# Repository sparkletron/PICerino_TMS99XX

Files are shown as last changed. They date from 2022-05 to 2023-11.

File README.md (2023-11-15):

# PICerino TMS VDP

Test Board and Software Library for TI TMS992X and TMS9118 video display processors.

author: Jay Convertino  

date: 2022.04.23  

license: MIT (software/Hardware)

## Release Versions
### Current
  - v2.1.0 - Improved video circuit for the TMS9118.

### Past
  - v2.0.0 - Improved video circuit that actually works.
  - v1.0.0 - Improved video circuit and TMS9118 schematic added.
  - v0.5.0 - First version with old video circuit.
  - none
  
## Requirements
### Hardware
  - KiCad
  
### Software
  - xc8 compiler
  
## Information

### Directory Listing:

  - docs - Data documents for various ICs.
  - schematic - KiCad schematic
    - TMS9118 - Contains a schematic for a TMS9118 board with video circuit (v2).
    - TMS992X - Contains a schematic for a TMS992X board with video circuit (v2).
  - src - Any source code for the project.
    - lib_picTMS99XX folder contains a library with test program for picerino. See readme.md in this directory for details.

### Usage
  This is made to be used with the picerino development board. This uses the standard DRAM since there are plenty of them around from various venders. The idea is the test program with put the card through its paces. This is done by putting the VDP into all modes and testing all of its functions. Currently this is incomplete. GFX II, various sprite sizes and edge cases need testing. The other idea with this was to create a simple video circuit for YrYbY output to go to an upscaler and then to HDMI. The retrotink 2x works well with the output of this unit.

### Build
  Through hole components were selected for everything, except for the video circuit of the TMS9118. This something I had on hand. Production uses a double sided board.

### Video Output
  This video circuit is based on a few ideas. Mostly TMS-RGB for the use of the LM1881. All other design choices are from application datasheets and just trial and error. Main issue with TMS-RGB being used whole sale is it has all surface mount components and it isn't universal for TMS9918. The goal of this project was to output component or composite to the retro tink x2. TI's application data sheet is keying out the Yr/Yb color bursts with a decoulping cap passing the signal to a 4066 that just went to ground during sync. This in theory should work fine, but in practice you'll still see a bit of the burst. TMS-RGB used a sample and hold method, which worked great to the converter chip. Taking the TMS RGB and just using a quad switch to sample the Yb signal, then pass it to the other inputs that then use that sample when needed (see lm1881 connections). This method of using a quad switch eliminates the too much blue issue. It also results in a circuit that is only 3 ic's. A MAX394, ADG813, and LM1881. The opamp is setup to rebalance the colors per the TMS RGB Y+Yr+Yb findings. Again big thanks to them for spending the time to document how and what they did. Saved me a lot of work on this project.

### Issues
  N/A

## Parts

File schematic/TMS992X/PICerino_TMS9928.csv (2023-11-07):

# | Reference | Qty | Value | Footprint | DNP
1 | C1 | 1 | 10uF | Capacitor_THT:CP_Radial_D5.0mm_P2.50mm
2 | C2, C3, C4, C5, C6, C7, C8, C9, C13, C15, C16, C18, C19, C20, C23 | 15 | 100nF | Capacitor_THT:C_Disc_D4.7mm_W2.5mm_P5.00mm
3 | C10 | 1 | 2-5pf | Capacitor_THT:C_Rect_L10.0mm_W5.0mm_P5.00mm_P7.50mm
4 | C11 | 1 | 30pF | Capacitor_THT:C_Disc_D3.0mm_W1.6mm_P2.50mm
5 | C12 | 1 | 33pF | Capacitor_THT:C_Disc_D3.0mm_W1.6mm_P2.50mm
6 | C14, C27, C28 | 3 | 33uF | Capacitor_THT:CP_Radial_D5.0mm_P2.50mm
7 | C17, C21, C24, C26 | 4 | 220pf | Capacitor_THT:C_Disc_D4.7mm_W2.5mm_P5.00mm
8 | C22, C29, C30 | 3 | 470uF | Capacitor_THT:CP_Radial_D8.0mm_P5.00mm
9 | C25 | 1 | 10nF | Capacitor_THT:C_Disc_D4.7mm_W2.5mm_P5.00mm
10 | CON1 | 1 | PICERINO-EDGE | Connector_PCBEdge_EXT:PICERINO-EDGE
11 | D1 | 1 | D_Schottky | Diode_THT:D_DO-35_SOD27_P7.62mm_Horizontal
12 | J1 | 1 | Conn_01x02 | Connector_PinHeader_2.54mm:PinHeader_1x02_P2.54mm_Vertical
13 | J2, J3, J4, J10 | 4 | Conn_01x03 | Connector_PinHeader_2.54mm:PinHeader_1x03_P2.54mm_Vertical
14 | J5 | 1 | Y | RCJ-041:RCJ041_TS
15 | J6 | 1 | Yr | RCJ-041:RCJ041_TS
16 | J7 | 1 | Yb | RCJ-041:RCJ041_TS
17 | J8, J9 | 2 | Conn_01x08 | Package_SIP:SIP-8_19x3mm_P2.54mm
18 | R1 | 1 | 10K | Resistor_THT:R_Axial_DIN0207_L6.3mm_D2.5mm_P7.62mm_Horizontal
19 | R2, R4, R12, R13, R14 | 5 | 510R | Resistor_THT:R_Axial_DIN0207_L6.3mm_D2.5mm_P7.62mm_Horizontal
20 | R5 | 1 | 680k | Resistor_THT:R_Axial_DIN0207_L6.3mm_D2.5mm_P7.62mm_Horizontal
21 | R6 | 1 | 430R | Resistor_THT:R_Axial_DIN0207_L6.3mm_D2.5mm_P7.62mm_Horizontal
22 | R7, R9, R10 | 3 | 470R | Resistor_THT:R_Axial_DIN0207_L6.3mm_D2.5mm_P7.62mm_Horizontal
23 | R8, R17, R18 | 3 | 75R | Resistor_THT:R_Axial_DIN0207_L6.3mm_D2.5mm_P7.62mm_Horizontal
24 | R11 | 1 | 1K | Resistor_THT:R_Axial_DIN0207_L6.3mm_D2.5mm_P7.62mm_Horizontal
25 | R15 | 1 | 200R | Resistor_THT:R_Axial_DIN0207_L6.3mm_D2.5mm_P7.62mm_Horizontal
26 | R16 | 1 | 270R | Resistor_THT:R_Axial_DIN0207_L6.3mm_D2.5mm_P7.62mm_Horizontal
27 | TP1, TP2 | 2 | TestPoint | Connector_PinHeader_2.54mm:PinHeader_1x01_P2.54mm_Vertical
28 | U1 | 1 | LM1881 | Package_DIP:DIP-8_W7.62mm_LongPads
29 | U2 | 1 | AD813 | Package_DIP:DIP-14_W7.62mm_LongPads
30 | U3 | 1 | TMS9928A | Package_DIP:DIP-40_W15.24mm_LongPads
31 | U4 | 1 | NE5532 | Package_DIP:DIP-8_W7.62mm_LongPads
32 | U5, U6, U8, U9, U10, U11, U12, U13 | 8 | MK4516N | Package_DIP:DIP-16_W7.62mm_LongPads
33 | U7 | 1 | ADG453 | Package_DIP:DIP-16_W7.62mm_LongPads
34 | Y1 | 1 | Crystal | Crystal:Crystal_HC49-4H_Vertical

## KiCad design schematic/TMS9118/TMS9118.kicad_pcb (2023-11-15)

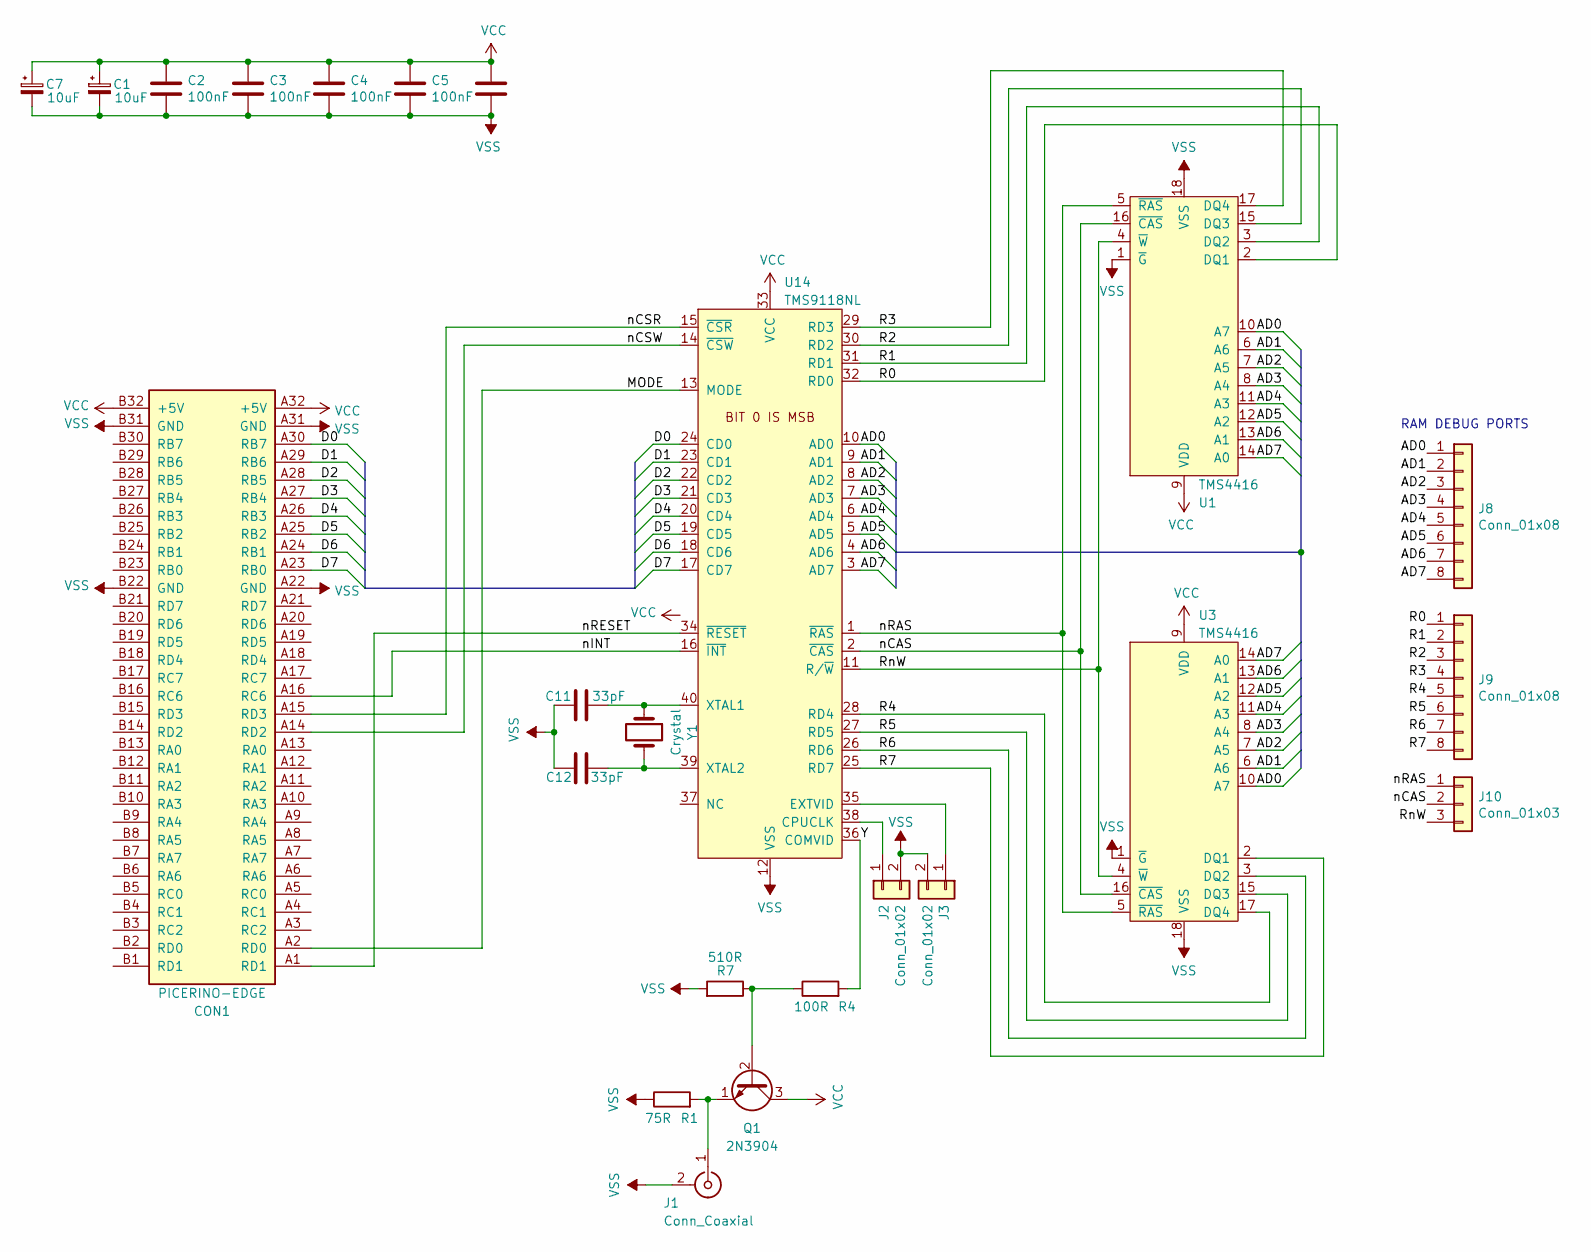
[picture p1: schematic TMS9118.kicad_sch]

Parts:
C1, C7: 10uF; CP_Radial_D5.0mm_P2.50mm
C2, C3, C4, C5, C6: 100nF; C_Disc_D4.7mm_W2.5mm_P5.00mm
C11, C12: 33pF; C_Disc_D3.0mm_W1.6mm_P2.50mm
CON1: PICERINO-EDGE
J1: Conn_Coaxial; RCJ041
J2, J3: Conn_01x02; PinHeader_1x02_P2.54mm_Vertical
J8, J9: Conn_01x08; SIP-8_19x3mm_P2.54mm
J10: Conn_01x03; PinHeader_1x03_P2.54mm_Vertical
Q1: 2N3904; TO-92_Wide
R1: 75R; R_Axial_DIN0207_L6.3mm_D2.5mm_P7.62mm_Horizontal
R4: 100R; R_Axial_DIN0207_L6.3mm_D2.5mm_P7.62mm_Horizontal
R7: 510R; R_Axial_DIN0207_L6.3mm_D2.5mm_P7.62mm_Horizontal
U1, U3: TMS4416; DIP-18_W7.62mm_LongPads
U14: TMS9118NL; DIP-40_W15.24mm_LongPads
Y1: Crystal; Crystal_HC49-4H_Vertical

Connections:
/AD0: J8.1, U1.10 (A7), U3.10 (A7), U14.10 (AD0)
/AD1: J8.2, U1.6 (A6), U3.6 (A6), U14.9 (AD1)
/AD2: J8.3, U1.7 (A5), U3.7 (A5), U14.8 (AD2)
/AD3: J8.4, U1.8 (A4), U3.8 (A4), U14.7 (AD3)
/AD4: J8.5, U1.11 (A3), U3.11 (A3), U14.6 (AD4)
/AD5: J8.6, U1.12 (A2), U3.12 (A2), U14.5 (AD5)
/AD6: J8.7, U1.13 (A1), U3.13 (A1), U14.4 (AD6)
/AD7: J8.8, U1.14 (A0), U3.14 (A0), U14.3 (AD7)
/D0: CON1.A30 (RB7), U14.24 (CD0)
/D1: CON1.A29 (RB6), U14.23 (CD1)
/D2: CON1.A28 (RB5), U14.22 (CD2)
/D3: CON1.A27 (RB4), U14.21 (CD3)
/D4: CON1.A26 (RB3), U14.20 (CD4)
/D5: CON1.A25 (RB2), U14.19 (CD5)
/D6: CON1.A24 (RB1), U14.18 (CD6)
/D7: CON1.A23 (RB0), U14.17 (CD7)
/MODE: CON1.A2 (RD0), U14.13 (MODE)
/R0: J9.1, U1.2 (DQ1), U14.32 (RD0)
/R1: J9.2, U1.3 (DQ2), U14.31 (RD1)
/R2: J9.3, U1.15 (DQ3), U14.30 (RD2)
/R3: J9.4, U1.17 (DQ4), U14.29 (RD3)
/R4: J9.5, U3.17 (DQ4), U14.28 (RD4)
/R5: J9.6, U3.15 (DQ3), U14.27 (RD5)
/R6: J9.7, U3.3 (DQ2), U14.26 (RD6)
/R7: J9.8, U3.2 (DQ1), U14.25 (RD7)
/RnW: J10.3, U1.4 (~W), U3.4 (~W), U14.11 (R/~W)
/Y: R4.2, U14.36 (COMVID)
/nCAS: J10.2, U1.16 (~CAS), U3.16 (~CAS), U14.2 (~CAS)
/nCSR: CON1.A15 (RD3), U14.15 (~CSR)
/nCSW: CON1.A14 (RD2), U14.14 (~CSW)
/nINT: CON1.A16 (RC6), U14.16 (~INT)
/nRAS: J10.1, U1.5 (~RAS), U3.5 (~RAS), U14.1 (~RAS)
/nRESET: CON1.A1 (RD1), U14.34 (~RESET)
unnamed: J1.1 (In), Q1.1 (E), R1.2
unnamed: J2.1, U14.38 (CPUCLK)
unnamed: J3.1, U14.35 (EXTVID)
unnamed: Q1.2 (B), R4.1, R7.1
unnamed: C11.2, U14.40 (XTAL1), Y1.1
unnamed: C12.1, U14.39 (XTAL2), Y1.2
VCC: C1.1, C2.1, C3.1, C4.1, C5.1, C6.1, C7.1, CON1.A32 (+5V), CON1.B32 (+5V), Q1.3 (C), U1.9 (VDD), U3.9 (VDD), U14.33 (VCC)
VSS: C1.2, C2.2, C3.2, C4.2, C5.2, C6.2, C7.2, C11.1, C12.2, CON1.A22 (GND), CON1.A31 (GND), CON1.B22 (GND), CON1.B31 (GND), J1.2 (Ext), J2.2, J3.2, R1.1, R7.2, U1.1 (~G), U1.18 (VSS), U3.1 (~G), U3.18 (VSS), U14.12 (VSS)

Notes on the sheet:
RAM DEBUG PORTS

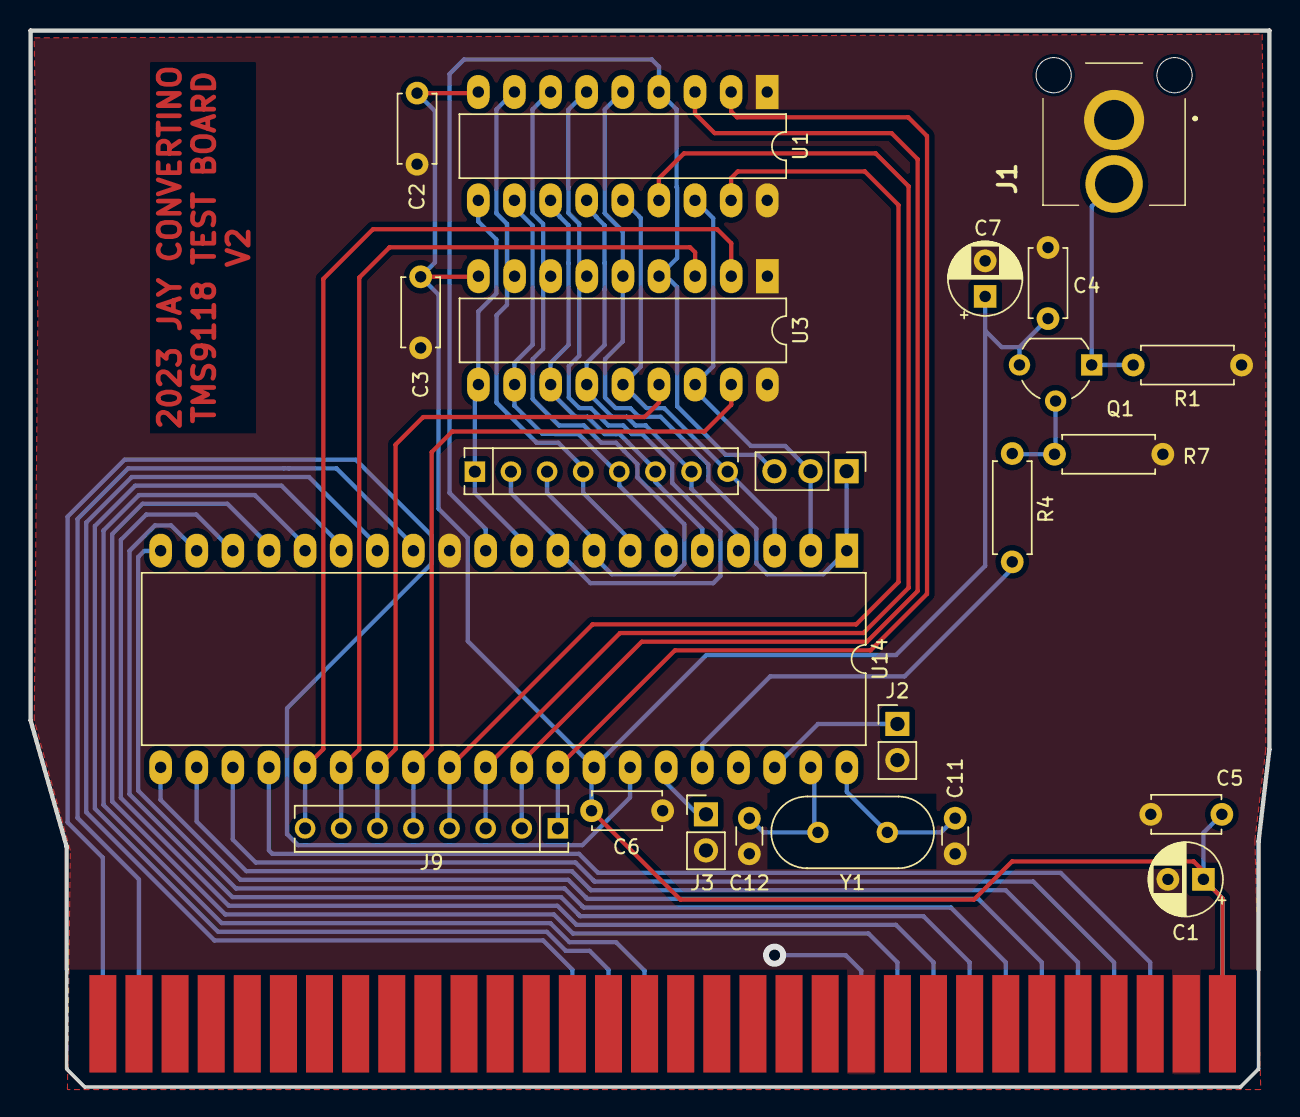
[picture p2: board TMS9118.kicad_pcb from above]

Board: 2 copper layers, 87.1 x 74.3 mm, 24 parts (0 on the bottom side), 41 nets.

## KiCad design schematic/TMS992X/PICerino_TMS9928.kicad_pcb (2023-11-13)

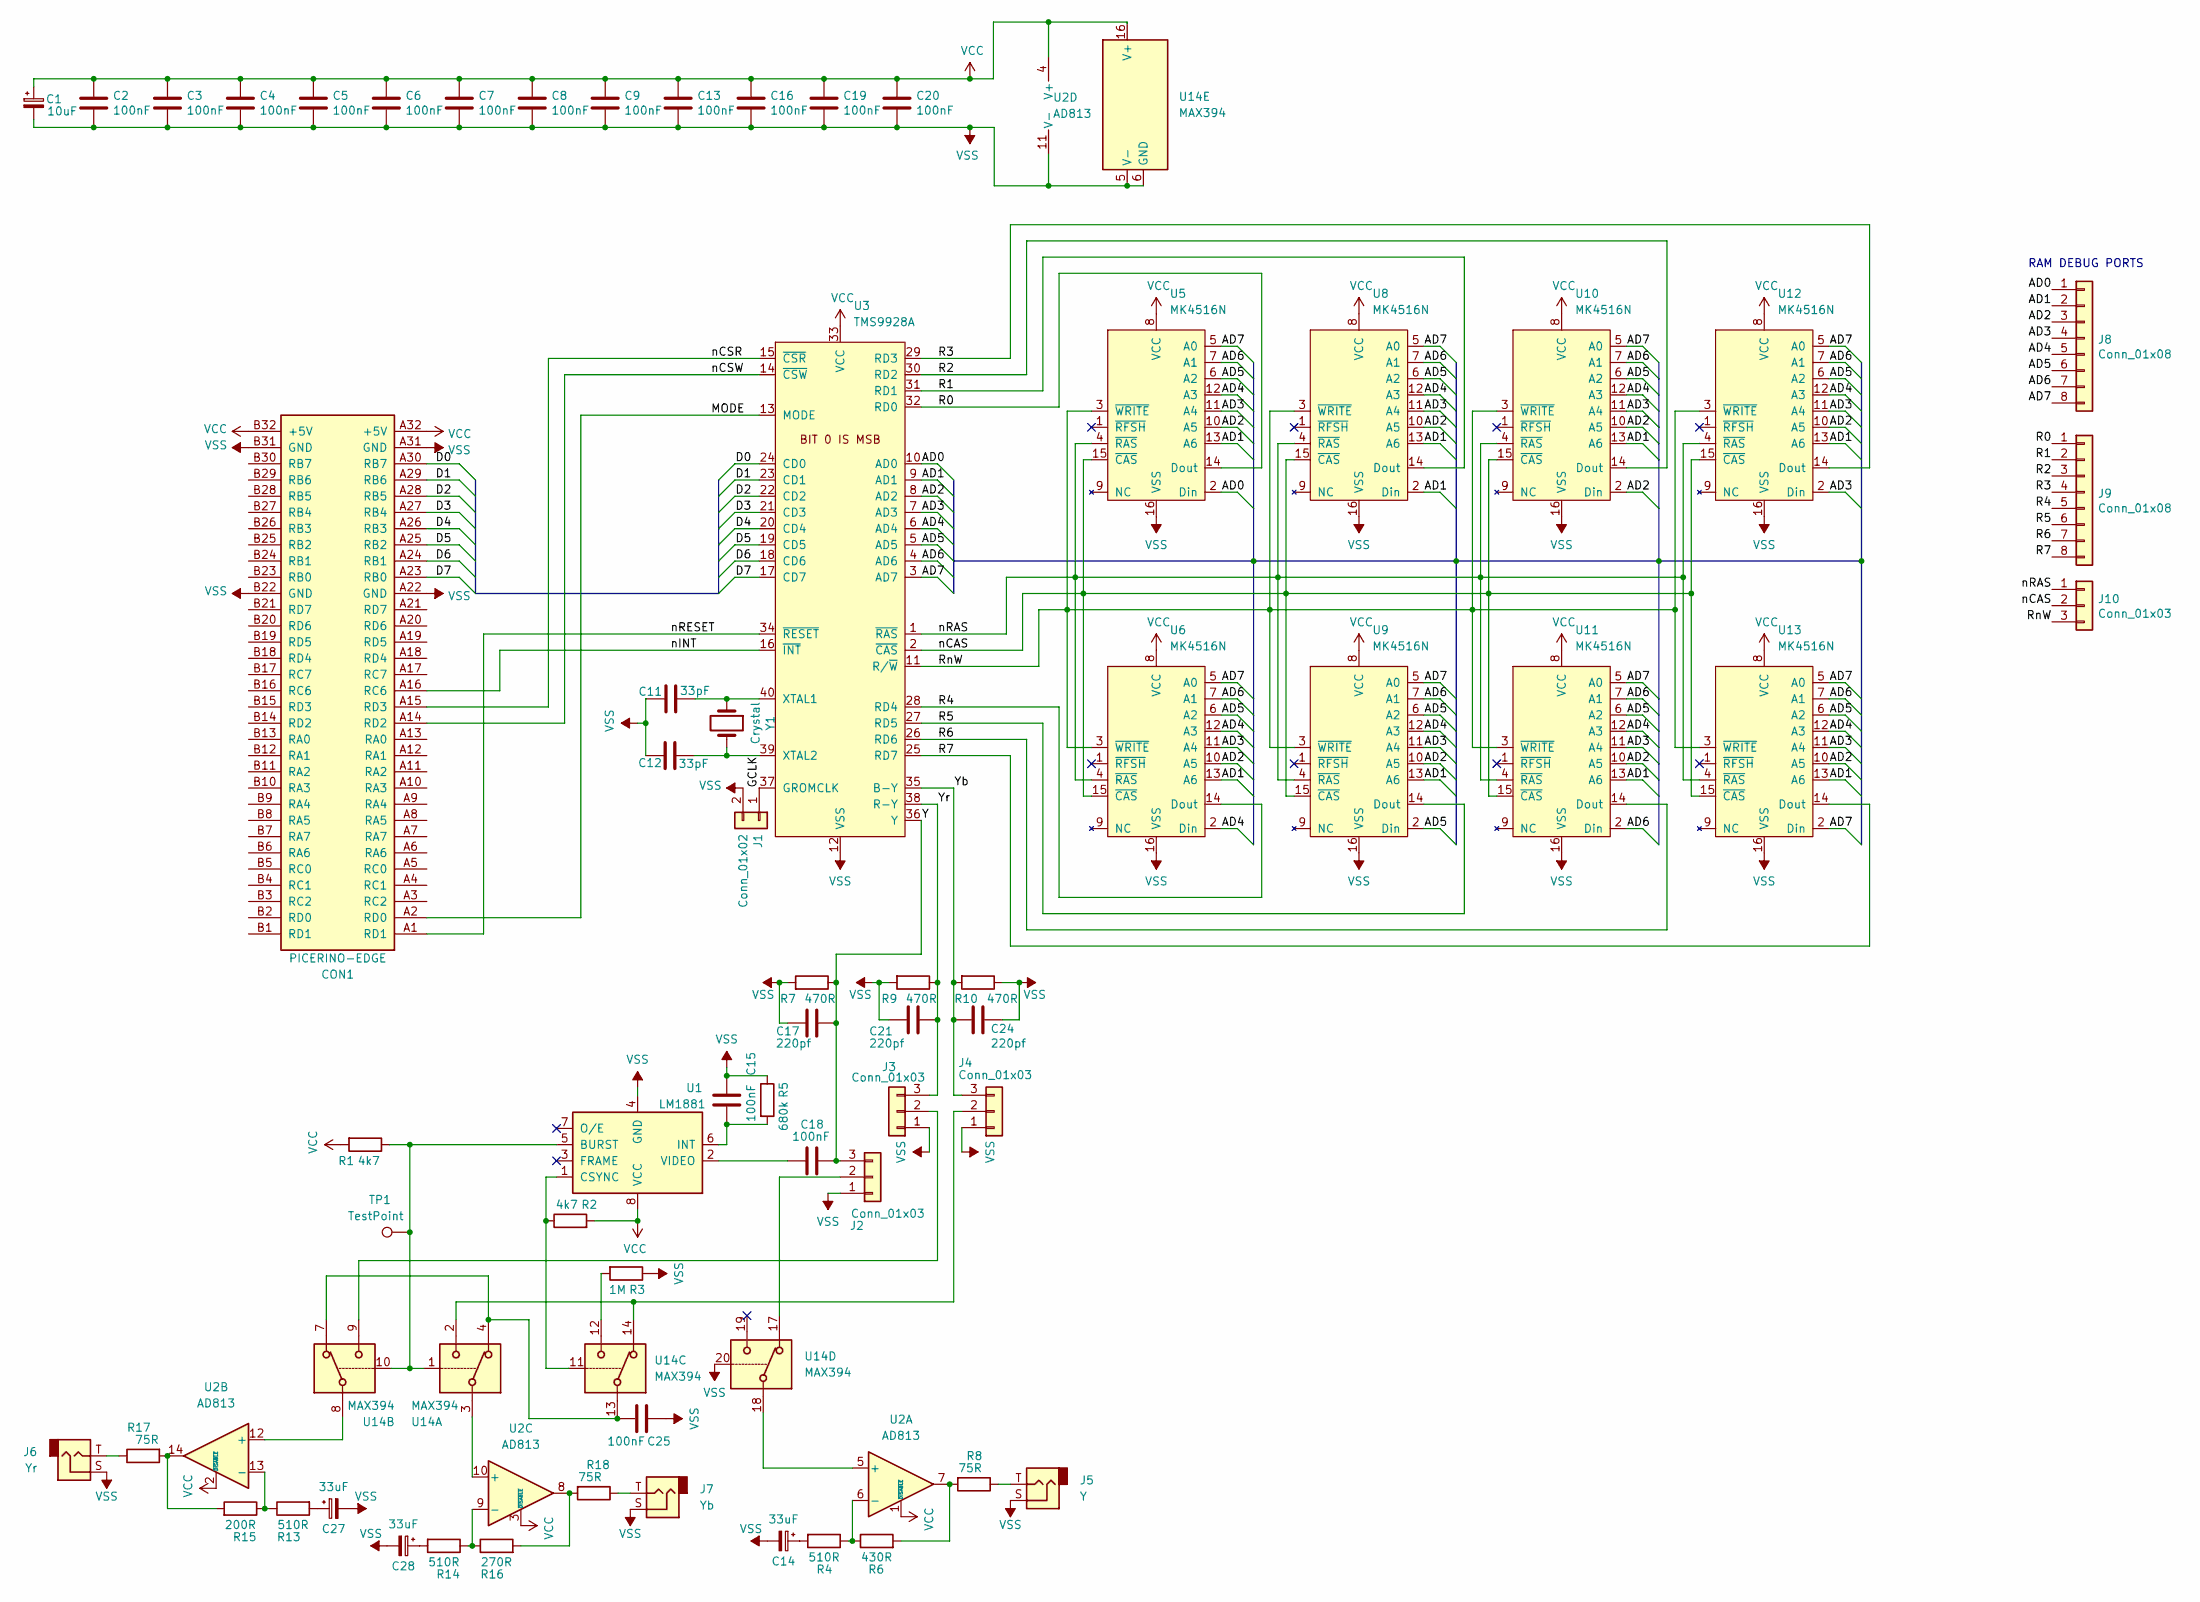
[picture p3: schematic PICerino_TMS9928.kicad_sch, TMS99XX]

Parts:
C1: 10uF; CP_Radial_D5.0mm_P2.50mm
C2, C3, C4, C5, C6, C7, C8, C9, C13, C15, C16, C18, C19, C20, C25: 100nF; C_Disc_D4.7mm_W2.5mm_P5.00mm
C11, C12: 33pF; C_Disc_D3.0mm_W1.6mm_P2.50mm
C14, C27, C28: 33uF; CP_Radial_D5.0mm_P2.50mm
C17, C21, C24: 220pf; C_Disc_D4.7mm_W2.5mm_P5.00mm
CON1: PICERINO-EDGE
J1: Conn_01x02; PinHeader_1x02_P2.54mm_Vertical
J2, J3, J4, J10: Conn_01x03; PinHeader_1x03_P2.54mm_Vertical
J5: Y; RCJ041_TS
J6: Yr; RCJ041_TS
J7: Yb; RCJ041_TS
J8, J9: Conn_01x08; SIP-8_19x3mm_P2.54mm
R1, R2: 4k7; R_Axial_DIN0207_L6.3mm_D2.5mm_P7.62mm_Horizontal
R3: 1M; R_Axial_DIN0207_L6.3mm_D2.5mm_P7.62mm_Horizontal
R4, R13, R14: 510R; R_Axial_DIN0207_L6.3mm_D2.5mm_P7.62mm_Horizontal
R5: 680k; R_Axial_DIN0207_L6.3mm_D2.5mm_P7.62mm_Horizontal
R6: 430R; R_Axial_DIN0207_L6.3mm_D2.5mm_P7.62mm_Horizontal
R7, R9, R10: 470R; R_Axial_DIN0207_L6.3mm_D2.5mm_P7.62mm_Horizontal
R8, R17, R18: 75R; R_Axial_DIN0207_L6.3mm_D2.5mm_P7.62mm_Horizontal
R15: 200R; R_Axial_DIN0207_L6.3mm_D2.5mm_P7.62mm_Horizontal
R16: 270R; R_Axial_DIN0207_L6.3mm_D2.5mm_P7.62mm_Horizontal
TP1: TestPoint; PinHeader_1x01_P2.54mm_Vertical
U1: LM1881; DIP-8_W7.62mm_LongPads
U2: AD813; DIP-14_W7.62mm_LongPads
U3: TMS9928A; DIP-40_W15.24mm_LongPads
U5, U6, U8, U9, U10, U11, U12, U13: MK4516N; DIP-16_W7.62mm_LongPads
U14: MAX394; DIP-20_W7.62mm_LongPads
Y1: Crystal; Crystal_HC49-4H_Vertical

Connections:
/AD0: J8.1, U3.10 (AD0), U5.2 (Din)
/AD1: J8.2, U3.9 (AD1), U5.13 (A6), U6.13 (A6), U8.2 (Din), U8.13 (A6), U9.13 (A6), U10.13 (A6), U11.13 (A6), U12.13 (A6), U13.13 (A6)
/AD2: J8.3, U3.8 (AD2), U5.10 (A5), U6.10 (A5), U8.10 (A5), U9.10 (A5), U10.2 (Din), U10.10 (A5), U11.10 (A5), U12.10 (A5), U13.10 (A5)
/AD3: J8.4, U3.7 (AD3), U5.11 (A4), U6.11 (A4), U8.11 (A4), U9.11 (A4), U10.11 (A4), U11.11 (A4), U12.2 (Din), U12.11 (A4), U13.11 (A4)
/AD4: J8.5, U3.6 (AD4), U5.12 (A3), U6.2 (Din), U6.12 (A3), U8.12 (A3), U9.12 (A3), U10.12 (A3), U11.12 (A3), U12.12 (A3), U13.12 (A3)
/AD5: J8.6, U3.5 (AD5), U5.6 (A2), U6.6 (A2), U8.6 (A2), U9.2 (Din), U9.6 (A2), U10.6 (A2), U11.6 (A2), U12.6 (A2), U13.6 (A2)
/AD6: J8.7, U3.4 (AD6), U5.7 (A1), U6.7 (A1), U8.7 (A1), U9.7 (A1), U10.7 (A1), U11.2 (Din), U11.7 (A1), U12.7 (A1), U13.7 (A1)
/AD7: J8.8, U3.3 (AD7), U5.5 (A0), U6.5 (A0), U8.5 (A0), U9.5 (A0), U10.5 (A0), U11.5 (A0), U12.5 (A0), U13.2 (Din), U13.5 (A0)
/D0: CON1.A30 (RB7), U3.24 (CD0)
/D1: CON1.A29 (RB6), U3.23 (CD1)
/D2: CON1.A28 (RB5), U3.22 (CD2)
/D3: CON1.A27 (RB4), U3.21 (CD3)
/D4: CON1.A26 (RB3), U3.20 (CD4)
/D5: CON1.A25 (RB2), U3.19 (CD5)
/D6: CON1.A24 (RB1), U3.18 (CD6)
/D7: CON1.A23 (RB0), U3.17 (CD7)
/GCLK: J1.1, U3.37 (GROMCLK)
/MODE: CON1.A2 (RD0), U3.13 (MODE)
/R0: J9.1, U3.32 (RD0), U5.14 (Dout)
/R1: J9.2, U3.31 (RD1), U8.14 (Dout)
/R2: J9.3, U3.30 (RD2), U10.14 (Dout)
/R3: J9.4, U3.29 (RD3), U12.14 (Dout)
/R4: J9.5, U3.28 (RD4), U6.14 (Dout)
/R5: J9.6, U3.27 (RD5), U9.14 (Dout)
/R6: J9.7, U3.26 (RD6), U11.14 (Dout)
/R7: J9.8, U3.25 (RD7), U13.14 (Dout)
/RnW: J10.3, U3.11 (R/~W), U5.3 (~WRITE), U6.3 (~WRITE), U8.3 (~WRITE), U9.3 (~WRITE), U10.3 (~WRITE), U11.3 (~WRITE), U12.3 (~WRITE), U13.3 (~WRITE)
/Y: C17.1, C18.1, J2.3, R7.1, U3.36 (Y)
/Yb: C24.2, J4.3, R10.2, U3.35 (B-Y)
/Yr: C21.1, J3.3, R9.1, U3.38 (R-Y)
/nCAS: J10.2, U3.2 (~CAS), U5.15 (~CAS), U6.15 (~CAS), U8.15 (~CAS), U9.15 (~CAS), U10.15 (~CAS), U11.15 (~CAS), U12.15 (~CAS), U13.15 (~CAS)
/nCSR: CON1.A15 (RD3), U3.15 (~CSR)
/nCSW: CON1.A14 (RD2), U3.14 (~CSW)
/nINT: CON1.A16 (RC6), U3.16 (~INT)
/nRAS: J10.1, U3.1 (~RAS), U5.4 (~RAS), U6.4 (~RAS), U8.4 (~RAS), U9.4 (~RAS), U10.4 (~RAS), U11.4 (~RAS), U12.4 (~RAS), U13.4 (~RAS)
/nRESET: CON1.A1 (RD1), U3.34 (~RESET)
unnamed: C14.1, R4.2
unnamed: C25.2, U14.4, U14.7, U14.13
unnamed: C27.1, R13.2
unnamed: C28.1, R14.2
unnamed: J2.2, U14.17
unnamed: J3.2, U14.9
unnamed: J4.2, U14.2, U14.14
unnamed: J5.T, R8.1
unnamed: J6.T, R17.1
unnamed: J7.T, R18.1
unnamed: R3.2, U14.12
unnamed: R6.2, R8.2, U2.7
unnamed: R15.2, R17.2, U2.14
unnamed: R16.2, R18.2, U2.8
unnamed: R1.1, TP1.1, U1.5 (BURST), U14.1, U14.10
unnamed: R2.1, U1.1 (CSYNC), U14.11
unnamed: C15.1, R5.2, U1.6 (INT)
unnamed: C18.2, U1.2 (VIDEO)
unnamed: U2.5 (+), U14.18
unnamed: R4.1, R6.1, U2.6 (-)
unnamed: U2.12 (+), U14.8
unnamed: R13.1, R15.1, U2.13 (-)
unnamed: U2.10 (+), U14.3
unnamed: R14.1, R16.1, U2.9 (-)
unnamed: C11.2, U3.40 (XTAL1), Y1.1
unnamed: C12.1, U3.39 (XTAL2), Y1.2
VCC: C1.1, C2.1, C3.1, C4.1, C5.1, C6.1, C7.1, C8.1, C9.1, C13.1, C16.1, C19.1, C20.1, CON1.A32 (+5V), CON1.B32 (+5V), R1.2, R2.2, U1.8 (VCC), U2.1 (~DISABLE), U2.2 (~DISABLE), U2.3 (~DISABLE), U2.4 (V+), U3.33 (VCC), U5.8 (VCC), U6.8 (VCC), U8.8 (VCC), U9.8 (VCC), U10.8 (VCC), U11.8 (VCC), U12.8 (VCC), U13.8 (VCC), U14.16 (V+)
VSS: C1.2, C2.2, C3.2, C4.2, C5.2, C6.2, C7.2, C8.2, C9.2, C11.1, C12.2, C13.2, C14.2, C15.2, C16.2, C17.2, C19.2, C20.2, C21.2, C24.1, C25.1, C27.2, C28.2, CON1.A22 (GND), CON1.A31 (GND), CON1.B22 (GND), CON1.B31 (GND), J1.2, J2.1, J3.1, J4.1, J5.S, J6.S, J7.S, R3.1, R5.1, R7.2, R9.2, R10.1, U1.4 (GND), U2.11 (V-), U3.12 (VSS), U5.16 (VSS), U6.16 (VSS), U8.16 (VSS), U9.16 (VSS), U10.16 (VSS), U11.16 (VSS), U12.16 (VSS), U13.16 (VSS), U14.5 (V-), U14.6 (GND), U14.20

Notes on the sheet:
RAM DEBUG PORTS

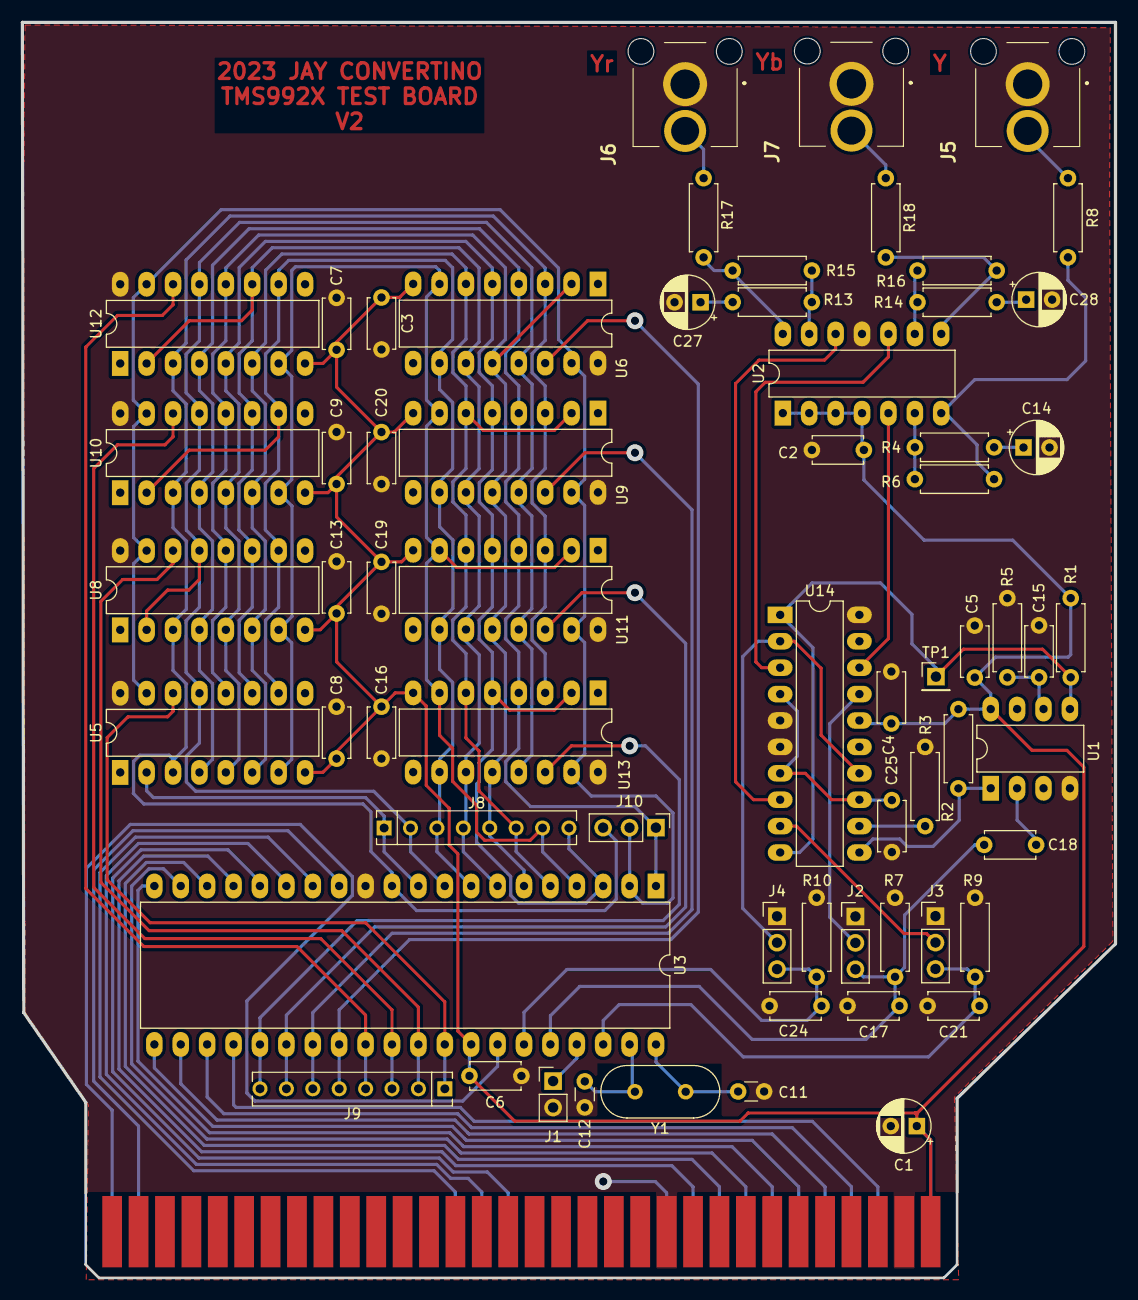
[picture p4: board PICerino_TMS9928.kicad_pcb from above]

Board: 2 copper layers, 105.2 x 120.8 mm, 65 parts (0 on the bottom side), 64 nets.

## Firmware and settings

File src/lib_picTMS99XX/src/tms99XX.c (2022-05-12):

/*******************************************************************************
 * @file    tms99XX.c
 * @brief   Library for TI TMS9918/28/29 video display processor.
 * @author  Jay Convertino(electrobs@gmail.com)
 * @date    2022.02.12
 * @details VDP default is:
 *          1  = nCSR
 *          1  = nCSW
 *          1  = MODE
 *          FF = dataTRIS (all data lines are input).
 *          This allows for mode setting and data direction setting to be
 *          skipped for read.
 *          16K is assumed for memory.
 * 
 * @license mit
 * 
 * Copyright 2022 Johnathan Convertino
 *
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
 * THE SOFTWARE IS PROVIDED "AS IS", WITHOUT WARRANTY OF ANY KIND, EXPRESS OR 
 * IMPLIED, INCLUDING BUT NOT LIMITED TO THE WARRANTIES OF MERCHANTABILITY, 
 * FITNESS FOR A PARTICULAR PURPOSE AND NONINFRINGEMENT. IN NO EVENT SHALL THE 
 * AUTHORS OR COPYRIGHT HOLDERS BE LIABLE FOR ANY CLAIM, DAMAGES OR OTHER 
 * LIABILITY, WHETHER IN AN ACTION OF CONTRACT, TORT OR OTHERWISE, ARISING 
 * FROM, OUT OF OR IN CONNECTION WITH THE SOFTWARE OR THE USE OR OTHER DEALINGS
 * IN THE SOFTWARE.
 ******************************************************************************/

#include <xc.h>
#include <stdint.h>

#include <tms99XX.h>

/** SEE MY PRIVATES **/
/*** read VDP status register ***/
inline uint8_t readVDPstatus(struct s_tms99XX * const p_tms99XX);
/*** read VDP vram ***/
inline int readVDPvram(struct s_tms99XX * const p_tms99XX, uint8_t *p_data, int size, int modLen);
/*** write VDP vram ***/
inline int writeVDPvram(struct s_tms99XX * const p_tms99XX, uint8_t const * const p_data, int size, int modLen);
/*** set write or read VDP vram address ***/
inline void writeVDPvramAddr(struct s_tms99XX * const p_tms99XX, uint16_t address, int rnw);
/*** write VDP registers ***/
inline void writeVDPregister(struct s_tms99XX * const p_tms99XX, uint8_t regNum, uint8_t data);
/*** graphics mode ***/
inline void initVDPmode(struct s_tms99XX * const p_tms99XX);
/*** reset vdp ***/
inline void resetVDP(struct s_tms99XX * const p_tms99XX);
/** bit setters **/
/*** NO NULL CHECK, USED INSIDE FUNCTIONS THAT DO THAT FIRST ***/
inline void setCtrlBitToOne(struct s_tms99XX * const p_tms99XX, uint8_t bitNum);
inline void setCtrlBitToZero(struct s_tms99XX * const p_tms99XX, uint8_t bitNum);

/** INITIALIZE AND FREE MY STRUCTS **/

/*** Initialize TMS99XX ports for correct I/O and set pin numbers ***/
void initTMS99XXport(struct s_tms99XX * const p_tms99XX, volatile unsigned char *p_dataTRIS, volatile unsigned char *p_ctrlTRIS, volatile unsigned char *p_intTRIS, uint8_t nCSR, uint8_t nCSW, uint8_t mode, uint8_t nreset, uint8_t nINT)
{
  /**** NULL Check ****/
  if(!p_tms99XX) return;
  
  if(!p_dataTRIS) return;
  
  if(!p_ctrlTRIS) return;
  
  if(!p_intTRIS) return;
  
  /**** populate TMS99XX structure ****/
  
  p_tms99XX->p_dataTRIS = p_dataTRIS;
  
  p_tms99XX->nCSR = nCSR;
  
  p_tms99XX->nCSW = nCSW;
  
  p_tms99XX->mode = mode;
  
  p_tms99XX->nreset = nreset;
  
  p_tms99XX->nINT = nINT;
  
  /**** setup control ports to default state ****/
  *p_tms99XX->p_dataTRIS = 0xFF;
  
  *p_ctrlTRIS &= (unsigned char)~((1 << nCSR) | (1 << nCSW) | (1 << mode) | (1 << nreset));
  
  *p_intTRIS |= (unsigned char)(1 << nINT);
}

/*** Initialize TMS99XX struct with ports to use for input output, must match direction registers above. ***/
void initTMS99XX(struct s_tms99XX * const p_tms99XX, uint8_t vdpMode, uint8_t backColor, volatile unsigned char *p_dataPortW, volatile unsigned char *p_dataPortR, volatile unsigned char *p_ctrlPortW, volatile unsigned char *p_intPortR)
{
  /**** NULL Check ****/
  if(!p_tms99XX) return;
  
  if(!p_dataPortW) return;
  
  if(!p_dataPortR) return;
  
  if(!p_ctrlPortW) return;
  
  if(!p_intPortR) return;
  
  /**** setup vdp struct ****/
  p_tms99XX->vdpMode = vdpMode;

  /**** clear register 0 ****/
  p_tms99XX->register0 = 0;
  
  /**** clear register 1, and set to 16k ****/
  p_tms99XX->register1 = (1 << VMEM_AMT_BIT);
  
  p_tms99XX->colorReg = (unsigned char)(backColor & 0x0F);
  
  /**** set vdp addresses ****/
  p_tms99XX->nameTableAddr = NAME_TABLE_ADDR;
  
  p_tms99XX->colorTableAddr = COLOR_TABLE_ADDR;
  
  p_tms99XX->patternTableAddr = PATTERN_TABLE_ADDR;
  
  p_tms99XX->spriteAttributeAddr = SPRITE_ATTRIBUTE_TABLE_ADDR;
  
  p_tms99XX->spritePatternAddr = SPRITE_PATTERN_TABLE_ADDR;
  
  /**** set VDP ports ****/
  p_tms99XX->p_dataPortW = p_dataPortW;
  
  p_tms99XX->p_dataPortR = p_dataPortR;
  
  p_tms99XX->p_ctrlPortW = p_ctrlPortW;
  
  p_tms99XX->p_intPortR = p_intPortR;
  
  /**** set ports to output default values ****/
  *p_tms99XX->p_dataPortW = 0x00;
  
  setCtrlBitToZero(p_tms99XX, p_tms99XX->nreset);
  
  setCtrlBitToOne(p_tms99XX, p_tms99XX->mode);
  
  setCtrlBitToOne(p_tms99XX, p_tms99XX->nCSR);
  
  setCtrlBitToOne(p_tms99XX, p_tms99XX->nCSW);
  
  /**** reset vdp ****/
  resetVDP(p_tms99XX);
  
  /**** init vdp with defaults ****/
  initVDPmode(p_tms99XX);
}

/*** Set the TMS99XX mode to one of 4. Text, Graphics I, Graphics II, and bitmap. ***/
void setTMS99XXmode(struct s_tms99XX * const p_tms99XX, uint8_t vdpMode)
{
  /**** NULL Check ****/
  if(!p_tms99XX) return;
  
  p_tms99XX->vdpMode = vdpMode;
  
  initVDPmode(p_tms99XX);
}

/*** Set the TMS99XX to blank the current sprite and pattern planes. ***/
void setTMS99XXblank(struct s_tms99XX * const p_tms99XX, uint8_t mode)
{
  /**** NULL Check ****/
  if(!p_tms99XX) return;
  
  /**** blank is active low, so for mode on (one) set reg bit to 0 ****/
  if(mode)
  {
    p_tms99XX->register1 &= (uint8_t)~(1 << BLK_SCRN_BIT);
  }
  else
  {
    p_tms99XX->register1 |= (uint8_t)(1 << BLK_SCRN_BIT);
  }
  
  writeVDPregister(p_tms99XX, REGISTER_1, p_tms99XX->register1);
}

/*** Set the TMS99XX to irq to enabled or disabled. ***/
void setTMS99XXirq(struct s_tms99XX * const p_tms99XX, uint8_t mode)
{
  /**** NULL Check ****/
  if(!p_tms99XX) return;
  
  if(mode)
  {
    p_tms99XX->register1 |= (uint8_t)(1 << IRQ_BIT);
  }
  else
  {
    p_tms99XX->register1 &= (uint8_t)~(1 << IRQ_BIT);
  }
  
  writeVDPregister(p_tms99XX, REGISTER_1, p_tms99XX->register1);
}

/*** Set the TMS99XX to sprite size to 8x8 or 16x16. ***/
void setTMS99XXspriteSize(struct s_tms99XX * const p_tms99XX, uint8_t mode)
{
  /**** NULL Check ****/
  if(!p_tms99XX) return;
  
  if(mode)
  {
    p_tms99XX->register1 |= (uint8_t)(1 << SPRITE_SIZE_BIT);
  }
  else
  {
    p_tms99XX->register1 &= (uint8_t)~(1 << SPRITE_SIZE_BIT);
  }
  
  writeVDPregister(p_tms99XX, REGISTER_1, p_tms99XX->register1);
}

/*** Set the TMS99XX to sprite magnify to on or off (double set size). ***/
void setTMS99XXspriteMagnify(struct s_tms99XX * const p_tms99XX, uint8_t mode)
{
  /**** NULL Check ****/
  if(!p_tms99XX) return;
  
  if(mode)
  {
    p_tms99XX->register1 |= (uint8_t)(1 << SPRITE_MAG_BIT);
  }
  else
  {
    p_tms99XX->register1 &= (uint8_t)~(1 << SPRITE_MAG_BIT);
  }
  
  writeVDPregister(p_tms99XX, REGISTER_1, p_tms99XX->register1);
}
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

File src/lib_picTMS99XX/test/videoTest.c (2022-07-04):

/*******************************************************************************
 * @file      videoTEST.c
 * @author    Jay Convertino
 * @date      2022.03.01
 * @brief     Test PICerino TMS99XX card.
 ******************************************************************************/

#include <xc.h>
#include <stdint.h>
#include <tms99XX.h>
#include <tms99XXascii.h>

#define SPRITES_8X8_NUM   5
#define SPRITES_16X16_NUM 4

/* configuration bits */
#pragma config PLLSEL   = PLL3X
#pragma config CFGPLLEN = ON
#pragma config CPUDIV   = NOCLKDIV
#pragma config LS48MHZ  = SYS48X8
#pragma config FOSC     = INTOSCIO
#pragma config PCLKEN   = OFF
#pragma config FCMEN    = OFF
#pragma config IESO     = OFF
#pragma config nPWRTEN  = OFF
#pragma config BOREN    = OFF
#pragma config BORV     = 190
#pragma config nLPBOR   = OFF
#pragma config WDTEN    = OFF
#pragma config WDTPS    = 32768
#pragma config CCP2MX   = RC1
#pragma config PBADEN   = OFF
#pragma config MCLRE    = OFF

/* used since chip is read-modify write only */
unsigned char g_porteBuffer = 0;

void main(void) 
{
  /* happy fun time variables */
  int       index = 0;
  int       row = 0;
  int       col = 0;
  int       spriteIndex = 0;
  uint16_t  freq = 0;
  uint8_t   attn = 0;
  uint8_t   shiftRate = 0;
  uint8_t   color = 0;
  uint8_t   temp = 0;
  
  /* contains ti chip object */
  struct s_tms99XX tms99XX;
  
  char helloWorld[] = "Hello World!!!";
  
  char tag[] = "2022 Jay Convertino";
  
  char gfxi[] = "GFX I";
  
  char gfximag[] = "GFX I MAG";

  char gfxlarge[] = "GFX I LARGE";

  char gfxlargeMag[] = "GFX I L MAG";
  
  char txtmode[] = "TXT";
  
  /* 8x8 sprites */
  struct s_tms99XX_spritePatternTable8x8 tms8x8sprites[] =
  {
    {{0x99, 0x66, 0x66, 0x99, 0x99, 0x66, 0x66, 0x99}}, //ship 1
    {{0x00, 0x18, 0x24, 0xFF, 0xFF, 0x24, 0x18, 0x00}}, //ship 2
    {{0x24, 0x3C, 0x18, 0x3C, 0x66, 0x7E, 0xC3, 0xFF}}, //ship 3
    {{0x24, 0x24, 0x24, 0x3C, 0x18, 0xFF, 0x66, 0xFF}}, //ship 4
    {{0x81, 0x42, 0x3C, 0x18, 0x3C, 0x66, 0xFF, 0xFF}}  //ship 5
  };

  /* 16x16 sprites */
  struct s_tms99XX_spritePatternTable16x16 tms16x16Sprites[] =
  {
    {{0x01, 0x03, 0x23, 0x73, 0x3B, 0x19, 0x0C, 0x00, 0x3C, 0xF8, 0x63, 0x06, 0x0C, 0x0C, 0x18, 0x00,
      0x00, 0x00, 0x0C, 0x38, 0x70, 0x40, 0x5F, 0x38, 0x20, 0x30, 0x9C, 0xCE, 0xC2, 0xE0, 0x60, 0x20}}, // dark pedals
    {{0x00, 0x08, 0x0C, 0x0C, 0x04, 0x06, 0xF2, 0x3C, 0x00, 0x06, 0x1C, 0x19, 0x33, 0x23, 0x03, 0x01,
      0x40, 0x60, 0x60, 0xC2, 0x8E, 0xBC, 0x20, 0x00, 0x1F, 0x4E, 0x60, 0x30, 0x18, 0x1C, 0x08, 0x00}}, // light pedals
    {{0x00, 0x00, 0x00, 0x00, 0x00, 0x00, 0x00, 0x01, 0x01, 0x00, 0x00, 0x00, 0x00, 0x00, 0x00, 0x00,
      0x00, 0x00, 0x00, 0x00, 0x00, 0x00, 0x00, 0x80, 0x80, 0x00, 0x00, 0x00, 0x00, 0x00, 0x00, 0x00}}, // center
    {{0x00, 0x00, 0x00, 0x00, 0x00, 0x00, 0x01, 0x02, 0x02, 0x01, 0x00, 0x00, 0x00, 0x00, 0x00, 0x00,
      0x00, 0x00, 0x00, 0x00, 0x00, 0x00, 0x80, 0x40, 0x40, 0x80, 0x00, 0x00, 0x00, 0x00, 0x00, 0x00}}  // center ring
  };
  
  /* sprites 16x16 */
  union u_tms99XX_spriteAttributeTable largeSprites[SPRITES_16X16_NUM] = {0};

  /* sprites 8x8 */
  union u_tms99XX_spriteAttributeTable sprites[SPRITES_8X8_NUM] = {0};

  /* colors for bitmap bars */
  union u_tms99XX_BMPpixelBlock tmsWhitePixelBlock = {.dataNibbles = {TMS_WHITE, TMS_WHITE, TMS_WHITE, TMS_WHITE}};

  union u_tms99XX_BMPpixelBlock tmsYellowPixelBlock = { .dataNibbles = {TMS_LIGHT_YELLOW, TMS_LIGHT_YELLOW, TMS_LIGHT_YELLOW, TMS_LIGHT_YELLOW}};

  union u_tms99XX_BMPpixelBlock tmsCyanPixelBlock = { .dataNibbles = {TMS_CYAN, TMS_CYAN, TMS_CYAN, TMS_CYAN}};

  union u_tms99XX_BMPpixelBlock tmsGreenPixelBlock = { .dataNibbles = {TMS_LIGHT_GREEN, TMS_LIGHT_GREEN, TMS_LIGHT_GREEN, TMS_LIGHT_GREEN}};

  union u_tms99XX_BMPpixelBlock tmsMagentaPixelBlock = { .dataNibbles = {TMS_MAGENTA, TMS_MAGENTA, TMS_MAGENTA, TMS_MAGENTA}};

  union u_tms99XX_BMPpixelBlock tmsRedPixelBlock = { .dataNibbles = {TMS_MEDIUM_RED, TMS_MEDIUM_RED, TMS_MEDIUM_RED, TMS_MEDIUM_RED}};

  union u_tms99XX_BMPpixelBlock tmsBluePixelBlock = { .dataNibbles = {TMS_DARK_BLUE, TMS_DARK_BLUE, TMS_DARK_BLUE, TMS_DARK_BLUE}};

  union u_tms99XX_BMPpixelBlock tmsBlackPixelBlock = { .dataNibbles = {TMS_BLACK, TMS_BLACK, TMS_BLACK, TMS_BLACK}};
  
  /* create struct to store ascii name table in order, removing first 32 null patterns */
  uint8_t nameTable[1 + (sizeof(c_tms99XX_ascii)/8) - 32] = {0};

  /* buffer array to scoll a text line */
  uint8_t scrollArray[40] = {0};
  
  /* create nametable to display all ascii characters */
  for(index = 0; index < sizeof(nameTable); index++)
  {
    /** offset to skip first 32 nulls **/
    nameTable[index] = (unsigned char)index + 32;
  }
  
  /* OSCCON SETUP */
  OSCCONbits.IRCF = 0x7;
  OSCCONbits.OSTS = 0;
  OSCCONbits.SCS  = 0x3;

  OSCCON2bits.PLLEN = 1;

  /* disable analog inputs */
  ANSELA = 0;
  ANSELB = 0;
  ANSELC = 0;
  ANSELD = 0;
  ANSELE = 0;
  
  /* enable pull ups */
  INTCON2bits.nRBPU = 0;
  WPUB = 0xFF;
  IOCB = 0;

  /* Port E set all to output */
  TRISE = 0;

  LATE = 0;

  g_porteBuffer = 4;

  /* wait for chip to be ready */
  __delay_ms(100);
  
  /* setup ports in struct for proper i/o */
  initTMS99XXport(&tms99XX, &TRISB, &TRISD, &TRISC, 3, 2, 0, 1, 6);
  
  /* setup tms9928 chip and finish setting up struct */
  initTMS99XX(&tms99XX, GFXI_MODE, TMS_TRANSPARENT, &LATB, &PORTB, &LATD, &PORTC);
  
  setTMS99XXtxtColor(&tms99XX, TMS_WHITE);
  
  /* SYSTEM TESTS */
  
  /* check all vram */
  if(!checkTMS99XXvram(&tms99XX))
  {
    LATE = g_porteBuffer;
    __delay_ms(2000);
    return;
  }
  
  /* clear all ti vdp memory */
  clearTMS99XXvramData(&tms99XX);
  
  /* test all 16 background colors */
  for(index = 0; index <= TMS_WHITE; index++)
  {
    setTMS99XXbackgroundColor(&tms99XX, (unsigned char)index);
    
    __delay_ms(1000);
  }
  
  /* set to TMS_CYAN for various tests */
  setTMS99XXbackgroundColor(&tms99XX, TMS_CYAN);
  
  /* MODE TESTS */
  /* FIRST: GFX I MODE, NORMAL 8x8 NO MAG*/
  setTMS99XXmode(&tms99XX, GFXI_MODE);
  
  /* ascii chars */
  setTMS99XXvramWriteAddr(&tms99XX, PATTERN_TABLE_ADDR);
  
  setTMS99XXvramData(&tms99XX, c_tms99XX_ascii, sizeof(c_tms99XX_ascii));
  
  /* write 2022 Jay Convertino on top line */
  setTMS99XXvramWriteAddr(&tms99XX, NAME_TABLE_ADDR);
  
  setTMS99XXvramData(&tms99XX, tag, sizeof(tag)); 
  
  setTMS99XXvramData(&tms99XX, gfxi, sizeof(gfxi));

  /* set sprite size to 8x8 */
  setTMS99XXspriteSize(&tms99XX, 0);
  
  /* set colors for all patterns */
  setTMS99XXvramWriteAddr(&tms99XX, COLOR_TABLE_ADDR);
  
  setTMS99XXvramConstData(&tms99XX, (TMS_DARK_BLUE << 4 | TMS_BLACK), 32);
  
  setTMS99XXvramWriteAddr(&tms99XX, SPRITE_PATTERN_TABLE_ADDR);
  
  setTMS99XXvramData(&tms99XX, tms8x8sprites, sizeof(tms8x8sprites));
  
  /* setup sprites */
  for(spriteIndex = 0; spriteIndex < SPRITES_8X8_NUM; spriteIndex++)
  {
    /** border is 8x8 **/
    /** display is 256x192 Y top is 255 (-1). -1 to 191 (191 is in border) */ 
    sprites[spriteIndex].dataNibbles.verticalPos = rand()%184;
    
    /** display is 256x192 X left is 0. 0 to 255 (255 is in border) */
    sprites[spriteIndex].dataNibbles.horizontalPos = rand()%248;
    
    sprites[spriteIndex].dataNibbles.name = (uint8_t)spriteIndex;
    
    sprites[spriteIndex].dataNibbles.earlyClockBit = 0;
    
    sprites[spriteIndex].dataNibbles.na = 0;
    
    sprites[spriteIndex].dataNibbles.colorCode = 15 - (uint8_t)spriteIndex;
  }
  
  /* write sprites attributes to vram */
  setTMS99XXvramWriteAddr(&tms99XX, SPRITE_ATTRIBUTE_TABLE_ADDR);
  
  setTMS99XXvramData(&tms99XX, sprites, sizeof(sprites));
  
  setTMS99XXvramSpriteTerm(&tms99XX, SPRITES_8X8_NUM);
  
  /* enable screen */
  setTMS99XXblank(&tms99XX, 0);
  
  /* test GFX sprite in no mag mode */
  for(index = 0; index < 1000; index++)
  {
    LATE = g_porteBuffer;
    
    g_porteBuffer = (unsigned char)(g_porteBuffer == 4 ? 1 : g_porteBuffer << 1);
    
    __delay_ms(10);
    
    for(spriteIndex = 0; spriteIndex < SPRITES_8X8_NUM; spriteIndex++)
    {
      if(sprites[spriteIndex].dataNibbles.verticalPos == 248)
      {
        sprites[spriteIndex].dataNibbles.verticalPos = 192;
      }
      
      sprites[spriteIndex].dataNibbles.verticalPos -= 1;
    }
    
    setTMS99XXvramWriteAddr(&tms99XX, SPRITE_ATTRIBUTE_TABLE_ADDR);
  
    setTMS99XXvramData(&tms99XX, sprites, sizeof(sprites));
  }
  
  /* SECOND: GFX sprite in mag mode */

  setTMS99XXspriteMagnify(&tms99XX, 1);
  
  /* write 2022 Jay Convertino on top line */
  setTMS99XXvramWriteAddr(&tms99XX, NAME_TABLE_ADDR);
  
  setTMS99XXvramData(&tms99XX, tag, sizeof(tag)); 
  
  setTMS99XXvramData(&tms99XX, gfximag, sizeof(gfximag));
  
  for(index = 0; index < 1000; index++)
  {
    LATE = g_porteBuffer;
    
    g_porteBuffer = (unsigned char)(g_porteBuffer == 4 ? 1 : g_porteBuffer << 1);
    
    __delay_ms(10);
    
    for(spriteIndex = 0; spriteIndex < SPRITES_8X8_NUM; spriteIndex++)
    {
      if(sprites[spriteIndex].dataNibbles.verticalPos == 248)
      {
        sprites[spriteIndex].dataNibbles.verticalPos = 192;
      }
      
      sprites[spriteIndex].dataNibbles.verticalPos -= 1;
    }
    
    setTMS99XXvramWriteAddr(&tms99XX, SPRITE_ATTRIBUTE_TABLE_ADDR);
  
    setTMS99XXvramData(&tms99XX, sprites, sizeof(sprites));
  }
  
  /* THIRD: GFX I large sprite in no mag mode */

  /* disable screen */
  setTMS99XXblank(&tms99XX, 1);

  /* disable magnify */
  setTMS99XXspriteMagnify(&tms99XX, 0);

  /* write 2022 Jay Convertino on top line */
  setTMS99XXvramWriteAddr(&tms99XX, NAME_TABLE_ADDR);

  setTMS99XXvramData(&tms99XX, tag, sizeof(tag));

  setTMS99XXvramData(&tms99XX, gfxlarge, sizeof(gfxlarge));

  /* set sprite size to 16x16 */
  setTMS99XXspriteSize(&tms99XX, 1);

  /* set colors for all patterns */
  setTMS99XXvramWriteAddr(&tms99XX, COLOR_TABLE_ADDR);

  setTMS99XXvramConstData(&tms99XX, (TMS_MEDIUM_GREEN << 4 | TMS_BLACK), 32);

  /* SET TO GREEN */
  setTMS99XXbackgroundColor(&tms99XX, TMS_MEDIUM_GREEN);

  setTMS99XXvramWriteAddr(&tms99XX, SPRITE_PATTERN_TABLE_ADDR);

  setTMS99XXvramData(&tms99XX, tms16x16Sprites, sizeof(tms16x16Sprites));

  /* setup largeSprites */
  for(spriteIndex = 0; spriteIndex < SPRITES_16X16_NUM; spriteIndex++)
  {
    /** border is 8x8 **/
    /** display is 256x192 Y top is 255 (-1). -1 to 191 (191 is in border) **/
    largeSprites[spriteIndex].dataNibbles.verticalPos = 100;

    /** display is 256x192 X left is 0. 0 to 255 (255 is in border) **/
    largeSprites[spriteIndex].dataNibbles.horizontalPos = 128;

    /** sprites are offset by the number of chunks the large sprite takes up **/
    largeSprites[spriteIndex].dataNibbles.name = (uint8_t)spriteIndex * 4;

    largeSprites[spriteIndex].dataNibbles.earlyClockBit = 0;

    largeSprites[spriteIndex].dataNibbles.na = 0;

    switch(spriteIndex)
    {
      case 0:
        largeSprites[spriteIndex].dataNibbles.colorCode = TMS_DARK_BLUE;
        break;
      case 1:
        largeSprites[spriteIndex].dataNibbles.colorCode = TMS_CYAN;
        break;
      case 2:
        largeSprites[spriteIndex].dataNibbles.colorCode = TMS_LIGHT_YELLOW;
        break;
      case 3:
        largeSprites[spriteIndex].dataNibbles.colorCode = TMS_DARK_YELLOW;
        break;
    }

  }

  /* write sprites attributes to vram */
  setTMS99XXvramWriteAddr(&tms99XX, SPRITE_ATTRIBUTE_TABLE_ADDR);

  setTMS99XXvramData(&tms99XX, largeSprites, sizeof(largeSprites));

  setTMS99XXvramSpriteTerm(&tms99XX, SPRITES_16X16_NUM);

  /* enable screen */
  setTMS99XXblank(&tms99XX, 0);

  for(index = 0; index < 1000; index++)
  {
    LATE = g_porteBuffer;

    g_porteBuffer = (unsigned char)(g_porteBuffer == 4 ? 1 : g_porteBuffer << 1);

    __delay_ms(10);

    for(spriteIndex = 0; spriteIndex < SPRITES_16X16_NUM; spriteIndex++)
    {
      largeSprites[spriteIndex].dataNibbles.horizontalPos += 1;
    }

    setTMS99XXvramWriteAddr(&tms99XX, SPRITE_ATTRIBUTE_TABLE_ADDR);

    setTMS99XXvramData(&tms99XX, largeSprites, sizeof(largeSprites));
  }

  /* FOURTH: GFX I large sprite in mag mode */

  /* write 2022 Jay Convertino on top line */
  setTMS99XXvramWriteAddr(&tms99XX, NAME_TABLE_ADDR);

  setTMS99XXvramData(&tms99XX, tag, sizeof(tag));

  setTMS99XXvramData(&tms99XX, gfxlargeMag, sizeof(gfxlargeMag));

  /* test GFX sprite in mag mode */
  setTMS99XXspriteMagnify(&tms99XX, 1);
  
    for(index = 0; index < 1000; index++)
  {
    LATE = g_porteBuffer;

    g_porteBuffer = (unsigned char)(g_porteBuffer == 4 ? 1 : g_porteBuffer << 1);

    __delay_ms(10);

    for(spriteIndex = 0; spriteIndex < SPRITES_16X16_NUM; spriteIndex++)
    {
      largeSprites[spriteIndex].dataNibbles.horizontalPos -= 1;
    }

    setTMS99XXvramWriteAddr(&tms99XX, SPRITE_ATTRIBUTE_TABLE_ADDR);

    setTMS99XXvramData(&tms99XX, largeSprites, sizeof(largeSprites));
  }

  LATE = 0;
  
  /* FIFTH: multicolor bitmap mode */

  /* SET TO BLACK */
  setTMS99XXbackgroundColor(&tms99XX, TMS_BLACK);

  /* disable screen */
  setTMS99XXblank(&tms99XX, 1);

  /* disable mag mode */
  setTMS99XXspriteMagnify(&tms99XX, 0);
  
  /* clear all ti vdp memory */
  clearTMS99XXvramData(&tms99XX);

  /* test multicolor bitmap mode */
  setTMS99XXmode(&tms99XX, BMP_MODE);

  /* write to pattern table */
  setTMS99XXvramWriteAddr(&tms99XX, PATTERN_TABLE_ADDR);

  /*
   * write white pixel block 4 times (8 bytes total, each block contains 2 bytes).
   * then write next, and the next and so on every 4... so for 8 colors thats 4*8 total
   * for 32 times. Every 4++ changes block to write.
   */
  for(index = 0; index < 32; index++)
  {
    if(index < 4)
    {
      setTMS99XXvramData(&tms99XX, &tmsWhitePixelBlock, sizeof(tmsWhitePixelBlock));
    }
    else if(index < 8)
    {
      setTMS99XXvramData(&tms99XX, &tmsYellowPixelBlock, sizeof(tmsYellowPixelBlock));
    }
    else if(index < 12)
    {
      setTMS99XXvramData(&tms99XX, &tmsCyanPixelBlock, sizeof(tmsCyanPixelBlock));
    }
    else if(index < 16)
    {
      setTMS99XXvramData(&tms99XX, &tmsGreenPixelBlock, sizeof(tmsGreenPixelBlock));
    }
    else if(index < 20)
    {
      setTMS99XXvramData(&tms99XX, &tmsMagentaPixelBlock, sizeof(tmsMagentaPixelBlock));
    }
    else if(index < 24)
    {
      setTMS99XXvramData(&tms99XX, &tmsRedPixelBlock, sizeof(tmsRedPixelBlock));
    }
    else if(index < 28)
    {
      setTMS99XXvramData(&tms99XX, &tmsBluePixelBlock, sizeof(tmsBluePixelBlock));
    }
    else
    {
      setTMS99XXvramData(&tms99XX, &tmsBlackPixelBlock, sizeof(tmsBlackPixelBlock));
    }
  }

  /* write to name table */
  setTMS99XXvramWriteAddr(&tms99XX, NAME_TABLE_ADDR);
  /*
   * populate name table... Row 0 is 0 for 4, then 1 for 4 till reaching 32.
   * Each row repeats this. There are 24 rows.
   */
  for(row = 0; row < 24; row++)
  {
    for(col = 0; col < 8; col++)
    {
      setTMS99XXvramConstData(&tms99XX, (uint8_t)col, 4);
    }
  }

  /* enable screen */
  setTMS99XXblank(&tms99XX, 0);

  /* test all 16 background colors */
  for(index = 0; index <= TMS_WHITE; index++)
  {
    setTMS99XXbackgroundColor(&tms99XX, (unsigned char)index);

    __delay_ms(1000);
  }

  /* disable screen */
  setTMS99XXblank(&tms99XX, 1);

  /* clear all ti vdp memory */
  clearTMS99XXvramData(&tms99XX);

  /* LAST: TEXT MODE */

  setTMS99XXmode(&tms99XX, TXT_MODE);
  
  /* SET TO BLACK */
  setTMS99XXbackgroundColor(&tms99XX, TMS_BLACK);
  
  /* write to pattern table */
  setTMS99XXvramWriteAddr(&tms99XX, PATTERN_TABLE_ADDR);

  setTMS99XXvramData(&tms99XX, c_tms99XX_ascii, sizeof(c_tms99XX_ascii));
  
  /* first ascii letter is space in this table, no image */
  setTMS99XXvramWriteAddr(&tms99XX, NAME_TABLE_ADDR);
  
  setTMS99XXvramConstData(&tms99XX, 0, 0x7FF);
  
  /* write all ascii text */
  setTMS99XXvramWriteAddr(&tms99XX, NAME_TABLE_ADDR);
  
  setTMS99XXvramData(&tms99XX, nameTable, sizeof(nameTable));
  
  /* write hello world on line 12 */
  setTMS99XXvramWriteAddr(&tms99XX, NAME_TABLE_ADDR + (40 * 11));
  
  setTMS99XXvramData(&tms99XX, helloWorld, sizeof(helloWorld));
  
  /* write 2022 Jay Convertino on last line (24 (23, offset 0)) */
  setTMS99XXvramWriteAddr(&tms99XX, NAME_TABLE_ADDR + (40 * 23));
  
  setTMS99XXvramData(&tms99XX, tag, sizeof(tag));
  
  setTMS99XXvramData(&tms99XX, txtmode, sizeof(txtmode));
  
  /* enable irq */
  /* when irq is enabled, polling will be used */
  /* disable to test 8 us delay method, no polling */
  setTMS99XXirq(&tms99XX, 1);
  
  /* enable screen */
  setTMS99XXblank(&tms99XX, 0);
  
  __delay_ms(1000);
  
  /* scroll hello world text forever */
  for(;;)
  {
    LATE = g_porteBuffer;
    g_porteBuffer = (unsigned char)(g_porteBuffer == 4 ? 1 : g_porteBuffer << 1);
    
    __delay_ms(50);
    
    /* read name table */
    setTMS99XXvramReadAddr(&tms99XX, NAME_TABLE_ADDR + (40 * 11));
    
    getTMS99XXvramData(&tms99XX, scrollArray, sizeof(scrollArray));
    
    /* shift all data from name table */
    /* write to name tabble */
    setTMS99XXvramWriteAddr(&tms99XX, NAME_TABLE_ADDR + (40 * 11));
    
    setTMS99XXvramData(&tms99XX, &scrollArray[1], sizeof(scrollArray)-1);
    
    setTMS99XXvramData(&tms99XX, &scrollArray[0], 1);
  }
}

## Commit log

2022-02-13 init commit, pcb built and only partially tested. Software incomplete
    [PICerino_TMS9928.kicad_pcb, PICerino_TMS9928.sch, dox.cfg]
2022-02-26 fixed divider values for addresses, created initial test program
    [videoTest.c]
2022-02-26 added 470 ohm load resistors to output of VDP pre TI spec (whoops)
    [PICerino_TMS9928.kicad_pcb, PICerino_TMS9928.sch]
2022-03-10 updated schematic with new features. 1) test points for dram testing. 2) jumpers to route video output signals for testing.
    [PICerino_TMS9928.kicad_pcb, PICerino_TMS9928.sch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]
2022-04-07 a few tweaks to tms9928 code. changed when data vs assert lines are timed. example now changes colors of background in a loop. This works, but the video output circuit has issues.
    [videoTest.c]
2022-04-08 schematic fix, 100nF cap is way too high a value and filters and the backporch of the signal (blurs it). 220pF is the value from a few TI example schematics. Works great, clear picture
    [PICerino_TMS9928.kicad_pcb, PICerino_TMS9928.sch]
2022-04-09 removed luma circuit, no need. added 75ohm voltage divider per the 2267 data sheet. do not populate for 6db increase, other wise use it for most applications.
    [PICerino_TMS9928.kicad_pcb, PICerino_TMS9928.sch]
2022-04-09 fixed spelling
    [PICerino_TMS9928.kicad_pcb, issue_txt.csv]
2022-04-15 change project name to TMS99XX, since recent changes will allow 18/28/29 to work
    [dox.cfg]
2022-04-23 spelling error and struct init mistake fixed
    [tms99XX.c, videoTest.c]
2022-04-23 updated schematic of TMS9928. This will work for 9918, and 9929 as well. Only Y is needed for 9918, and 9929 requires a different crystal. One item to point out is this video circuit is only supposed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
    [PICerino_TMS9928.kicad_pcb, PICerino_TMS9928.sch, dox.cfg]
2022-04-24 fixed vramAddress setup: split read/write address set. had bytes in wrong order for ti to set vram address (ffs msb is 0). added const set for vram. added ram check.
    [tms99XX.c, videoTest.c]
2022-04-24 schematic cleanup in progress. changed address/write data lines to bus. cleaned up some component stuffs.
    [PICerino_TMS9928.kicad_pcb, PICerino_TMS9928.sch]
2022-04-24 add library files for kicad
2022-04-24 added text scroll. doesn't work very well, next feature is to add irq polling so that we can write data on vsync. Otherwise I have to add a delay or blank the screen each time
    [videoTest.c]
2022-04-25 updated vram read/write and address vram set to poll interrupt if the irq is set. it will also skip polling if blank is enabled
    [dox.cfg]
2022-04-25 updated library to return number of bytes that could possibly be written in polling method. Approx 1000 (4.3 mS / 4 us minus fudge factor). Changed xtal_freq to a compiler command line directive. Eas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
    [issue_txt.csv]
2022-04-25 fixed read indexing to reflec amount read
    [tms99XX.c]
2022-04-28 added delay method when irq is not enabled. irq doesn't seem to work at the moment for read? also read is not working correctly. Must be a timing issue.
    [tms99XX.c, videoTest.c]
2022-04-28 fixed irq polling method, readVDPstatus must be done after data transfer and not before. polling and delay method show same read data corruption. need to fix data timing.
    [tms99XX.c, videoTest.c]
2022-04-29 changed the method so input is default state. seems that the tms9928 keeps data asserted to the output after nCSR is pulsed high. Avoiding bus contention issues.
    [tms99XX.c]
2022-04-29 fixed mistake with setting mode after readVDPstatus. since 1 is always assumed to be set in that function. looks like text scroll issue is in the read and is a bit 0 flip. swapped ram without any fix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
    [tms99XX.c]
2022-04-29 change of default read/write/bitsets fixed vram read issue. scroll was orignally really dumb... total forgot about the 0th element issue :D. Changed it to my original idea which is now working... now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
    [videoTest.c]
2022-04-30 major change to video section. dark green seemed off. tested adg453 sending output to gnd on that negative sync pulse. worked well. using mostly ti's idea with a modern sync strip ic. decided to use 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
    [PICerino_TMS9928.kicad_pcb, PICerino_TMS9928.sch]
2022-04-30 pcb with video updates exported to gerber, and updated iso file for t-tech v4
    [PICerino_TMS9928.kicad_pcb, PICerino_TMS9928.sch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]
2022-04-30 added two connectors to break out lm1881 outputs. essentially this is so outputs can be setup to particular use case. this is not a great video circuit, the routing is sloppy in this version.
    [PICerino_TMS9928.kicad_pcb, PICerino_TMS9928.sch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]
2022-05-01 tested addition of tms99XXascii.h, const is compiled correctly into program memory space when included to test program.
    [videoTest.c]
2022-05-01 fixed ascii table, x and q have a mistake, and f and d are just missing so messed the f up. ;)
    [videoTest.c]
2022-05-01 added null offsets to ascii chars so C ascii strings won't need an offset. wastes space, but this is for easy testing and usage, not efficenty of code. Finished putting video test for TXT mode.
    [videoTest.c]
2022-05-03 changed from ansii c. unions can't be initialized by members in that standard. fixed some casting in the newer version. removed patter 6x8 since 8x8 is always used by 2 bits are ignored. working on G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
    [tms99XX.c, videoTest.c]
2022-05-12 sprite now works, test is broken for now. reversed the bit order in the packed struct. created a always transparent sprite. whoops
    [videoTest.c]
2022-05-12 created a method to terminate sprites per the datasheet. untested at this point. fixed videoTest to run GFXI and TXT mode. Both modes need more TLC, and the video circuit is needing attention due to 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
    [tms99XX.c, videoTest.c]
2022-06-13 major change to video circuit, first working version that does not suffer from over blue issue. This has only been tested to work with the retrotink x2. Since most YrYbY do not accept 240p and it nee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
    [PICerino_TMS9928.kicad_pcb, PICerino_TMS9928.sch]
2022-06-13 added info about video circuit, no proof reading, just needed to get it out of my head.
2022-06-17 fixed ascii issues, missing z and upper case M pixel in wrong spot
2022-06-19 added a bleader resistor, still need to test the circuit before creating final board.
    [PICerino_TMS9928.kicad_pcb, PICerino_TMS9928.sch]
2022-06-19 updated board to new zener diode bias design. After testing this provided the best adjustment range. Could use some more work to simply it and check failure conditions.
    [PICerino_TMS9928.kicad_pcb, PICerino_TMS9928.sch]
2022-06-23 added weak pullups to bus, fixes noise issues that could cause glitches
    [videoTest.c]
2022-06-23 updated variable capacitor pads to be a bit larger
    [PICerino_TMS9928.kicad_pcb, PICerino_TMS9928.sch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]
2022-07-04 using new kicad 6.X, changed files and includes a backup of the old project
    [PICerino_TMS9928.kicad_pcb, PICerino_TMS9928.kicad_sch, PICerino_TMS9928.sch]
2023-01-16 added mit license to hardware
    [PICerino_TMS9928.kicad_sch]
2023-06-11 major changes to original schematic, video circuit is redone to avoid issues with shifting DC values. Op amp resistors changed to ratios from TMS RGB to help correct color output for retrotink.
    [PICerino_TMS9928.kicad_pcb, PICerino_TMS9928.kicad_sch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]
2023-06-11 added first version of TMS9118 test board
    [TMS9118.kicad_pcb, TMS9118.kicad_sch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]
2023-06-11 cleanup repo to remove old schematic, add new datasheets for TMS9118 parts
    [PICerino_TMS9928.kicad_pcb, PICerino_TMS9928.kicad_sch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]
2023-11-07 added new switch and sample video chip to simplify video output. work in progress.
    [PICerino_TMS9928.csv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]
2023-11-13 initial commit of v2 tms992X board
    [PICerino_TMS9928.kicad_pcb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]
2023-11-15 fixed tms9118 video output, opa832 failed
    [TMS9118.kicad_pcb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]
2024-03-25 added license file to root
    [TMS9118.kicad_sch]
